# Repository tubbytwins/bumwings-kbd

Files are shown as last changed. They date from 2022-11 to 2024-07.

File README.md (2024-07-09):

# Introduction
BumWings is an ergonomic keyboard design that has several variants with different key configurations.  Some variants use the Waveshare RP2040-zero board which features a Raspberry Pi RP2040 MCU.  Other variants use the Xiao Seeed family of controllers.  Additionally, I've created a new variant (64-key) that uses a nice!nano or compatible MCU.  These designs represent my first attempts at an all-new keyboard PCB design, but obviously I have been influenced by many other keyboard designs (including open-source, closed-source and commercial).

## Design and Implementation

BumWings uses an "un-split" angled ergonomic matrix that has columnar stagger with moderate pinky splay, and features dual inverted T-clusters and modest thumb key clusters.  It is a fairly large board that also gives space for the hands to stay apart and rest at an angle, which works well for me.

The controller board can either be soldered directly to the PCB, or socketed pin headers can alternately be used.

Credit is given to Pete Johanson for the Xiao footprint, circuit design and other aspects from his [revxlp keyboard design](https://gitlab.com/lpgalaxy/revxlp).

This design uses Kailh "Choc" PG1350 key switches.  The board can either be used bare or installed in a case.  For those who prefer a case, I have uploaded a set of PCB case files for a Corne-style board arrangement (with both top plate and bottom plate).  Other case options are still a work in progress.  I am open to using a 3D-printed case, but currently lack the capability (and I don't have a 3D printer); interested individuals who want to help me develop a 3D-printed case should contact me.

## Revisions

The original designs (labeled as "v001", committed in December 2022 and January 2023) represent my first attmept to create a keyboard PCB design.  I learned several things, including the undeniable fact that relatively large PCBs are somewhat more expensive to produce. 

I also learned that my hand-soldering skills were **not** that great.  

These learnings were applied to the "revised" or "remixed" designs (labeled as "v001R", committed in July 2023) which improve on the original "v001" design in some subtle ways.  These are in the "v001R" subdirectory.  I recommend that new users start with the designs in the "v001R" subdirectory.

## Pictures - Work in Progress

Here is a picture of my first prototype build of the initial "v001" RP2040 variant with 54 keys.  It has Kailh Choc Robin switches (mostly).

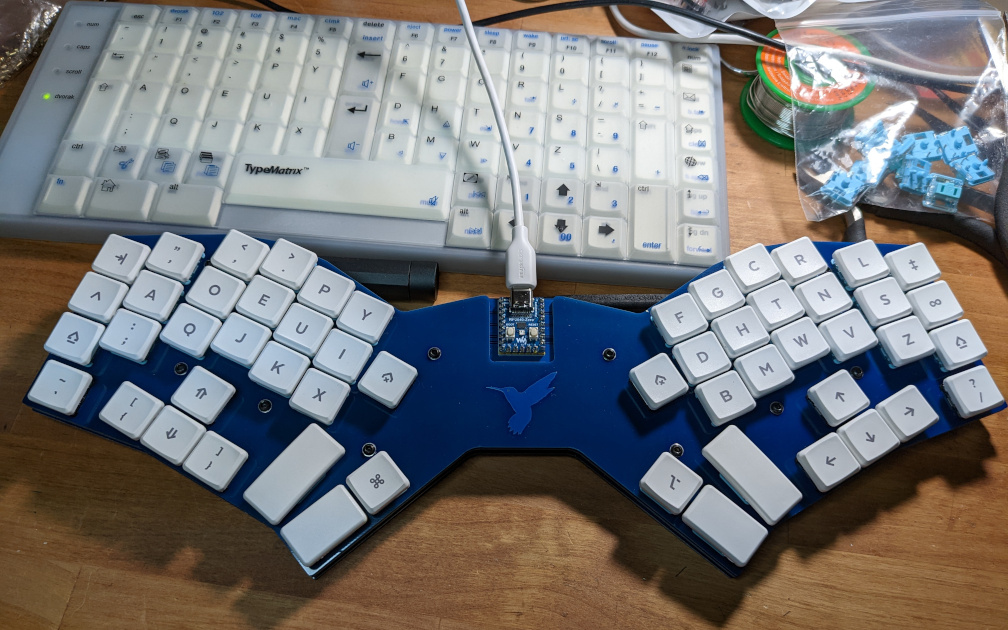
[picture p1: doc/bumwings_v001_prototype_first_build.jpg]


Here is a picture of the new "v001R" RP2040 variant with 64 keys.  This is now my "daily driver" keyboard.  It has Kailh Choc Brown switches (mostly).

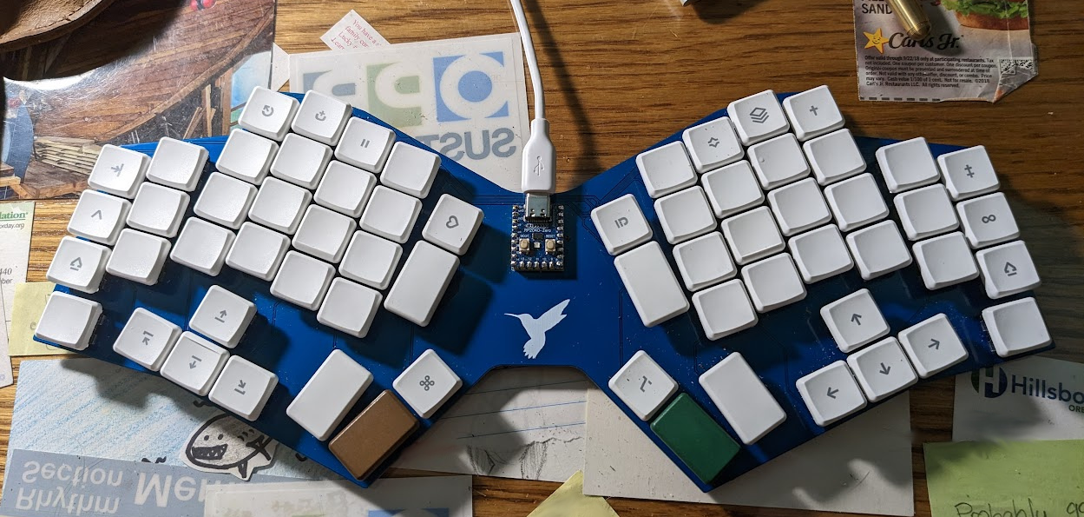
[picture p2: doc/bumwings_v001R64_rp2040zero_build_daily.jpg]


Here are two pictures of the new "v001R" Xiao variant with 64 keys.  This keyboard will be a gift for a friend.  It has Kailh Choc Jade switches (mostly).

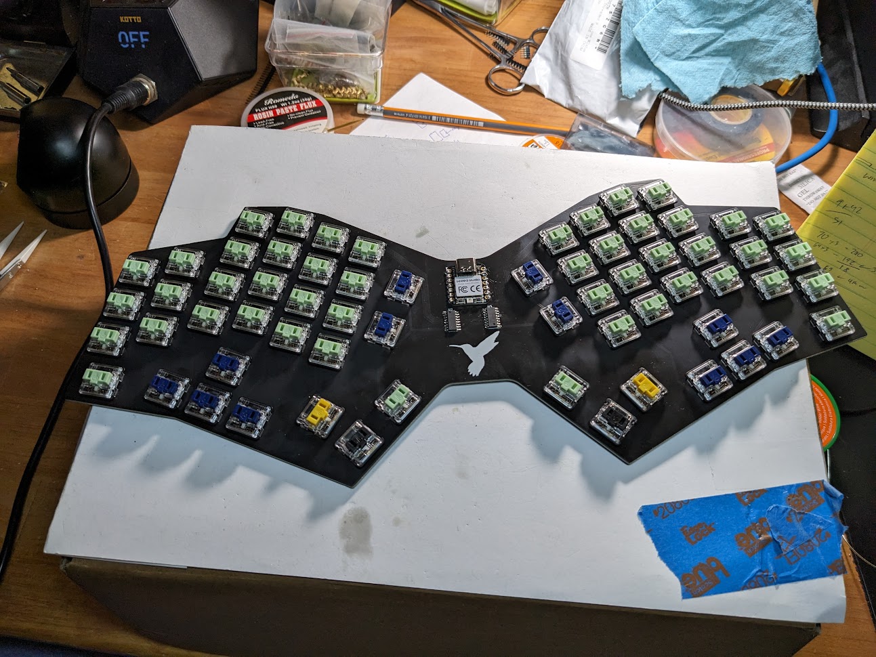
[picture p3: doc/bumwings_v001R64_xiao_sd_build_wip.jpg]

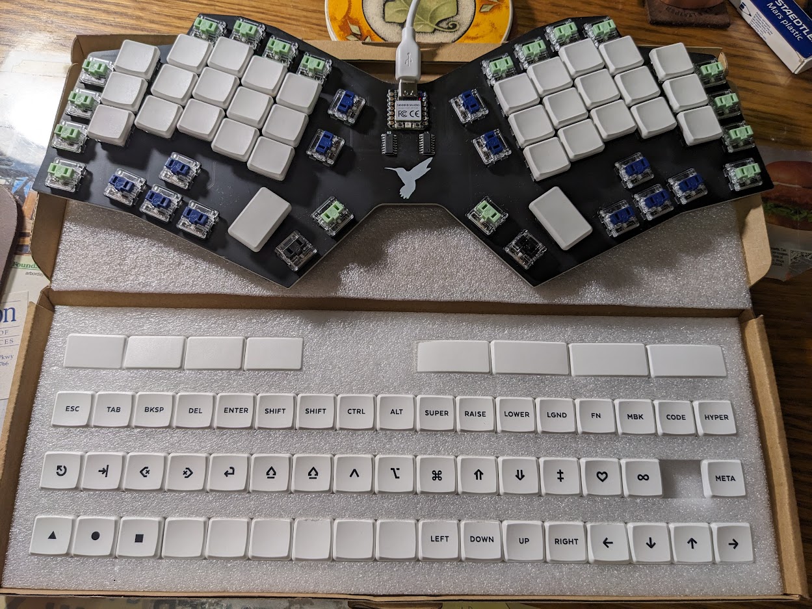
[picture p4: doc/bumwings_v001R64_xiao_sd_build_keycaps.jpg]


Here's another board, this one using the excellent Kailh Choc Sunset switches (mostly) with custom keycaps.

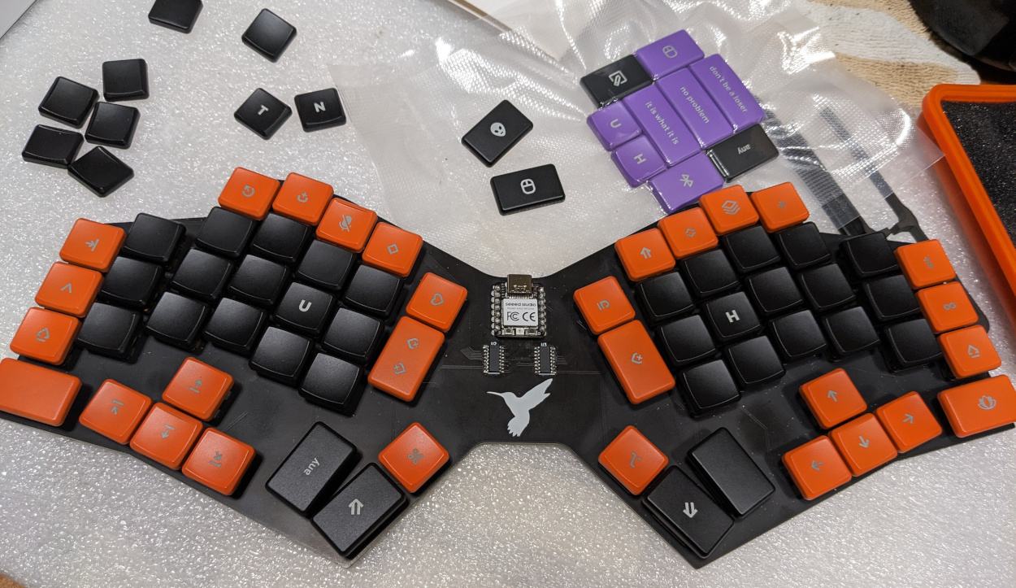
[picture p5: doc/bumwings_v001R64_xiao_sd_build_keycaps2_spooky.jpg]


(more pictures coming soon)

## Future Directions

Update 2024/July: I have some new things to show!

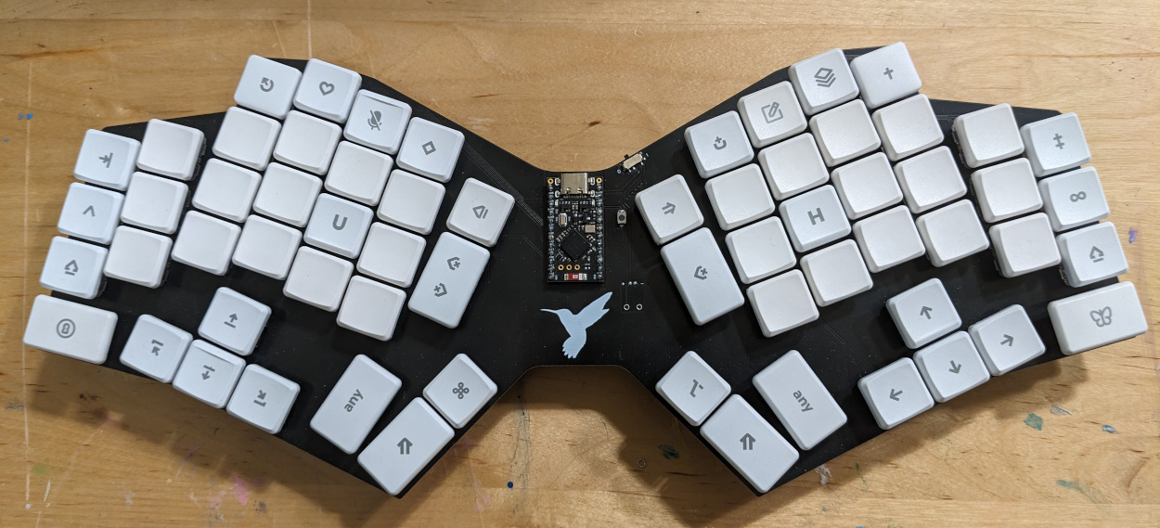
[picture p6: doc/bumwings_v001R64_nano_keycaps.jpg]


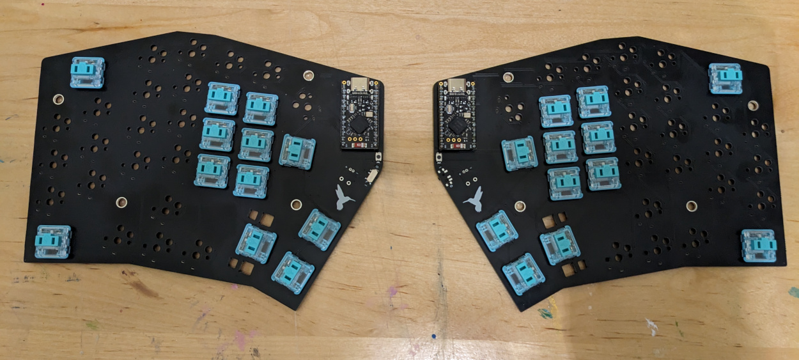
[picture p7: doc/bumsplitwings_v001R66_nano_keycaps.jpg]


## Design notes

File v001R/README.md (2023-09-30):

# V001R

I used JLCPCB to build the prototype PCBs for this version.  These work nicely, perhaps even better than the original "v001" designs.

## List of Variants

*   "pcb_R55_rp2040zero_sd" - simplified, remixed, 55-key direct-soldered PCB based on the Waveshare RP2040 "zero" controller
*   "pcb_R55_xiao_sd" - simplified, remixed, 55-key direct-soldered PCB based on the Seeed Xiao controller
*   "pcb_R64_rp2040zero_sd" - simplified, remixed, 64-key direct-soldered PCB based on the Waveshare RP2040 "zero" controller
*   "pcb_R64_xiao_sd" - simplified, remixed, 64-key direct-soldered PCB based on the Seeed Xiao controller
*   "pcb_R64_nano_sd" - simplified, remixed, 64-key direct-soldered PCB based on the nice!nano controller (and its derivatives)

## Explanation

These variants are different from the "v001" designs in several ways:

*   The overall length of the board was reduced, by about 1 inch.  This brings the hands closer together, but it's still a comfortable arrangement (at least for me).
*   The two hands were rotated "outwards" (i.e., left hand counter-clockwise, right hand clockwise) by a few degrees.  It's a subtle change that helps to reduce the overall width of the board.
*   The shift registers from "v001" (which are 74HC595PW components, in TSSOP-16 size) are now 74HC595D components (in SOIC-16 size) as the former were quite difficult to hand-solder (at least for me).  I messed up at least one prototype board with the TSSOP-16 components, then I learned that the SOIC-16 components were significantly less prone to soldering mishaps.
*   All components are now attached to the top side of the PCB (instead of the bottom side).
*   The case plates were removed, and the new designs are single-PCB caseless builds.  However, you are free to build a case around these if needed.
*   I switched away from the Kailh Choc hot-swap sockets, and went for direct-soldered switches instead.  I have nothing against the hot-swap sockets, but wanted the board design and construction to be simpler for these variants.

I also took the liberty of experimenting with the layout and the number of keys, as follows:

*   The "R55" variants add an extra 1.5U key in the center (between the thumb modifier keys).  You can use this as a space bar, a dedicated enter (carriage return), a layer key or any modifier.
*   The "R64" boards add 10 keys along a new top row, above the alpha keys (for all fingers except the pinky).  You can use these for other commonly accessed symbols, macros, or even delete/tab keys as desired.  The thumb spacebars are also now 1.5U keys instead of 2U keys, and the thumb cluster has been moved upward slightly, in order to reduce the overall width of the board.  In practice, 1.5U spacebars are quite usable, and you could probably use 1.75U spacebars (if the key caps were available).

## Pictures

The board renders for the 55-key and 64-key Waveshare RP2040-zero variants are shown below:

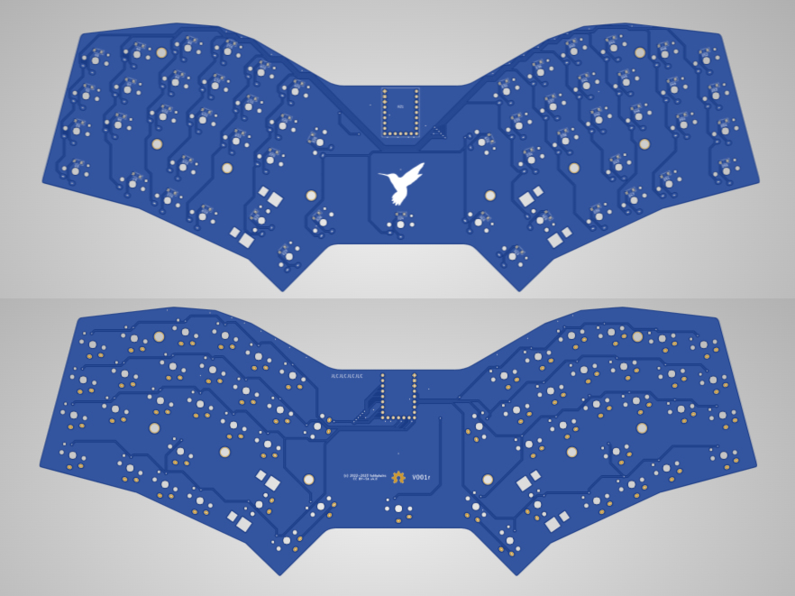
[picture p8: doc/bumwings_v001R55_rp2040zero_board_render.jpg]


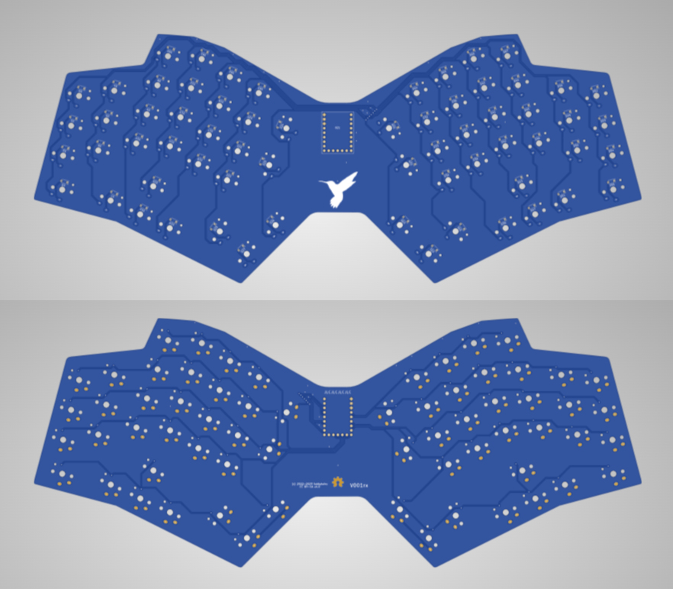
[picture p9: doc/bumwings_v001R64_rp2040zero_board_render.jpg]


The board renders for the 55-key and 64-key Xiao Seeed variants are shown below:

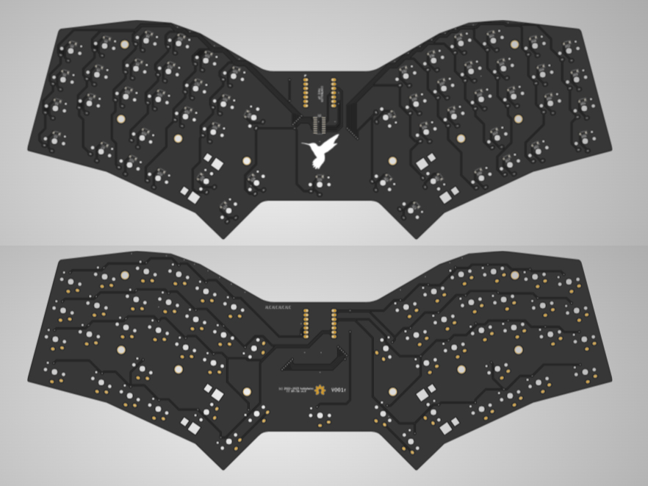
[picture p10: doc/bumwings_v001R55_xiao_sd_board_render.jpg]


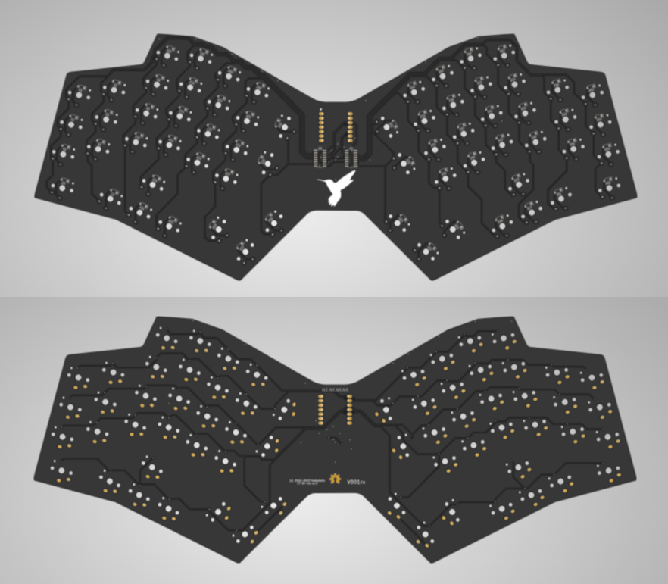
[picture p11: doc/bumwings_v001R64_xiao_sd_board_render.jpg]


The board render for the 64-key nice!nano variant is shown below:

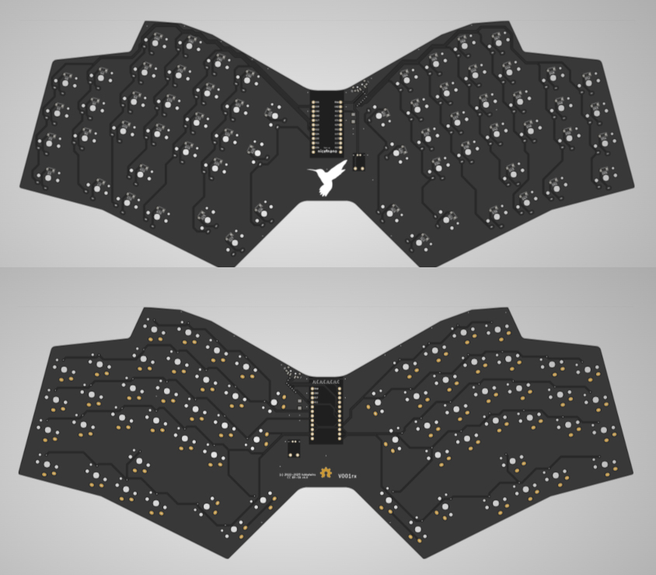
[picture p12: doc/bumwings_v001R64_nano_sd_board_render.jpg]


(I haven't made a 55-key nice!nano variant yet.  If anyone's interested, please feel free to ask.)

## Bill of Materials

## All variants

Diodes:  D_SOD-123 (either 55x or 64x)

Sockets:  none (since key switches are direct-soldered)

Key caps:  MBK (either plain, or with legends, at your discretion)

Other resistors/etc:  none

### Waveshare RP2040 variant

MCU:     Waveshare RP2040 "zero" (23-pin module with USB-C port) - you can find these on Amazon for a higher price, or on Aliexpress or eBay for a lower price.  They can either be plain, or with pre-soldered pin headers.

### Xiao Seeed variant

MCU:     Xiao Seeed controller of your choice - you can find these from many suppliers.

Shift Register:  74HC595D (in SOIC-16 format) - you can find these from many suppliers.  The 55-key variants use 1 of these, and the 64-key variants use 2 of these in a chained configuration.

### nice!nano variant

MCU:     nice!nano, or one of the other derived controllers that you can find on Aliexpress for a lower price.  These will be soldered face-up.
Reset switch:  optional

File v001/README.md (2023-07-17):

# V001

I used JLCPCB to build the first prototype PCBs for this version.  It works nicely.

See "info.md" for more information about the background and inspiration for this keyboard design.

## List of Variants

*   "pcb_core52840" - 54-key hot-swap PCB based on the Waveshare Core52840 module
*   "pcb_rp2040zero" - 54-key hot-swap PCB based on Waveshare RP2040 "zero" controller
*   "pcb_xiao" - 54-key hot-swap PCB based on the Seeed Xiao controller
*   "pcb_xiao_s" - simplified 54-key direct-soldered PCB based on the Seeed Xiao controller

## Pictures

The board renders for the Waveshare RP2040-zero variant are shown below:

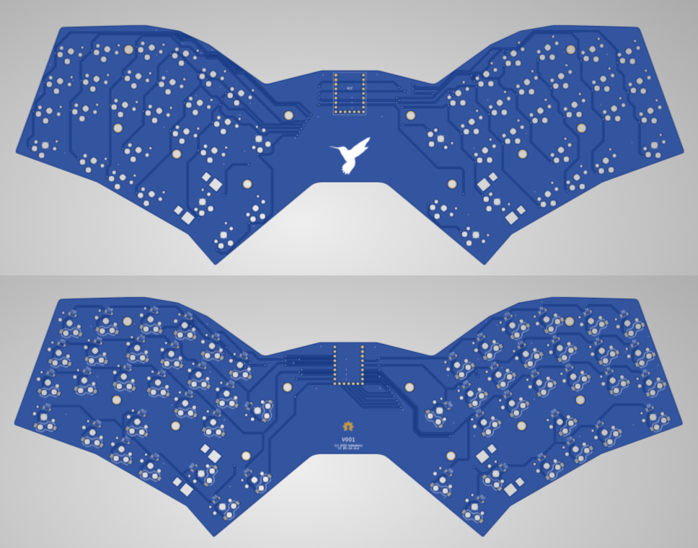
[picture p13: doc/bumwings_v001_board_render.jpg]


The board renders for the Xiao Seeed variant are shown below:

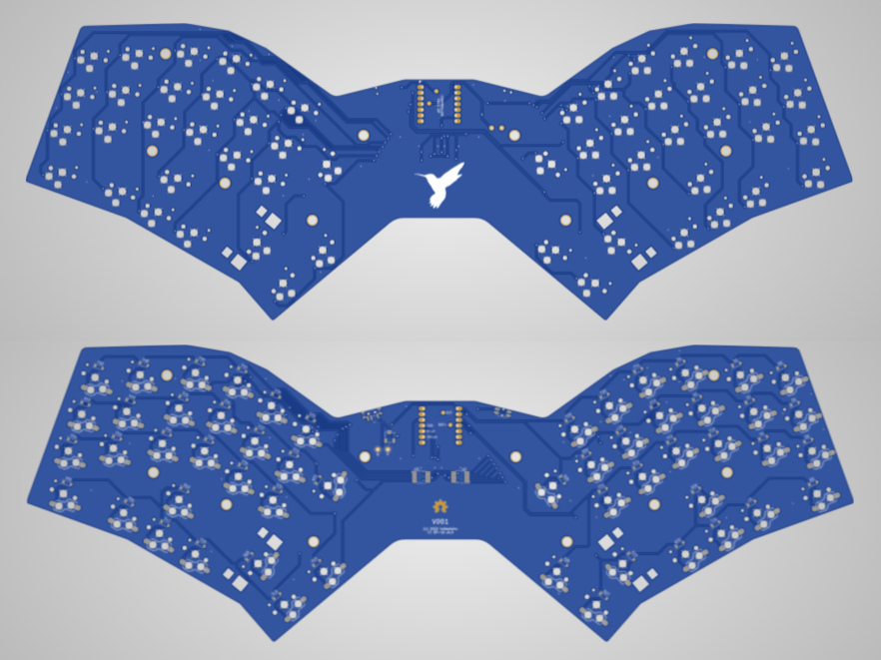
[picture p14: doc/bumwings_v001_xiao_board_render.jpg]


The board renders for the slightly simplified Xiao Seeed variant are shown below:

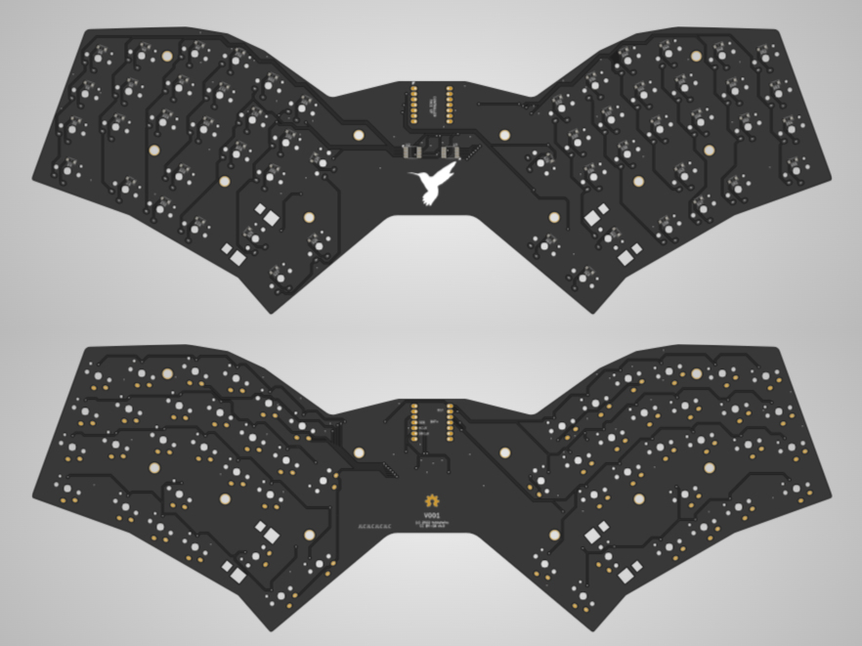
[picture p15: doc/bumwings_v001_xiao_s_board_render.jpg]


## Bill of Materials

## All variants

Diodes:  54x D_SOD-123

Sockets:  54x Kailh Choc hot-swap (for all variants except "pcb_xiao_s") (again, you will need 54 of them)

Key caps:  MBK (either plain, or with legends, at your discretion)

Other resistors/etc:  none

### Waveshare RP2040 variant

MCU:     Waveshare RP2040 "zero" (23-pin module with USB-C port) - you can find these on Amazon for a higher price, or on Aliexpress or eBay for a lower price.  They can either be plain, or with pre-soldered pin headers.

### Xiao Seeed variant

MCU:     Xiao Seeed controller of your choice - you can find these from many suppliers

Shift Register:  2x 74HC595PW or SN74HC595PW (in TSSOP-16 format) - you can find these from many suppliers, usually around USD $1.50 for a pack of 10

Reset switch and power switch:  optional, stay tuned...

### Xiao Seeed Simplified variant

MCU:    Xiao Seeed controller (as above)

Shift Register:  2x 74HC595PW or SN74HC595PW (in TSSOP-16 format)

No reset or power switch.  This variant is intended for non-wireless (and non-battery-powered) builds.  The Xiao Seeed RP2040 controller works very well for this variant, and I expect that the SAMD21 controller would also work very well.

For this variant, all components are direct-soldered to the front of the PCB (except the key switches, obviously).

### Waveshare Core52840 variant

MCU:     Waveshare Core52840 module, featuring Nordic Semiconductor's nRF52840

Alternate: HolyIOT 18010 module (which is apparently pin-compatible...)

Other components as follows:  (based heavily on Rafael Yumagulov's "Dao-Choc-BLE" board, but I replaced all 0603-size components with 1206-size components, to make it easier for hand-soldering)
https://github.com/yumagulovrn/dao-choc-ble

| Reference | Name | Package  | Value | Qty  |
|---|---|---|---|---|
| BT1 | JST | ? | 1.25mm 2pin 90° | 1 |
| C1-C2, C4-C5 | Capacitor | 1206 | 10uF | 4 |
| C3 | Capacitor | 1206 | 1nF | 1 |
| C6-C7 | Capacitor | 1206 | 4.7uF | 2 |
| D0-D55 | Diode | SOD-123  | 1N4148WS | 54 |
| D56 | Diode | SOD-123  | 1N5819W | 1 |
| D57 | LED | 1206 | BLUE | 1 |
| D58 | LED | 1206 | RED | 1 |
| F1 | Fuse | 1206 | 500mA | 1 |
| J1 | USB Receptacle | ? | ? | 1 |
| Q1 | P-Mosfet | SOT-23 | AO3401A | 1 |
| R1-R2 | Resistor | 1206 | 5.1k | 2 |
| R3 | Resistor | 1206 | 4.7 | 1 |
| R4 | Resistor | 1206 | 1M | 1 |
| R5a | Resistor | 1206 | 750k | 1 |
| R5b | Resistor | 1206 | 56k | 1 |
| R6-R7 | Resistor | 1206 | 1k | 2 |
| R8 | Resistor | 1206 | 2M | 1 |
| R9 | Resistor | 1206 | **RPROG**** | 1 |
| R10 | Resistor | 1206 | 100k | 1 |
| SW0-SW55 | Kailh Choc Hotswap Socket | ? | ? | 54 |
| SW56 | SPDT Switch | ? | MSK-12C02 | 1 |
| SW57 | Tactile Button | ? | TS-1086E | 1 |
| U1 | MCU | ? | Core52840 | 1 |
| U2 | ESD Protection IC | SOT-23-6 | USBLC6-2SC6 | 1 |
| U3 | Voltage Regulator IC | SOT-23-5 | XC6220 | 1 |
| U4 | Battery Charging IC | SOT-23-5 | MCP73831 | 1 |

In the Dao-Choc-BLE design, the designer offered an alternate value of 820k for "R5"; however, for such a voltage sensing circuit (for battery status) a resistor of 820k will give somewhat invalid values.  In my design, I opted to use two resistors that added up to 806k, which is the recommended value.

**RPROG**** Value depends on your battery capacity. For 300mAh battery should be 3.3K

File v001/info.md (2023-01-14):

# More Information about BumWings

## History and Design Goals

I've been using TypeMatrix keyboards (both EZR-2020 original and EZR-2030) for nearly 2 decades.  In 2004 (or so) I taught myself to touch-type in DVORAK, which resolved many ergonomic issues for me.  Long story short: I still love the TypeMatrix keyboards, but I started noticing that my hands and wrists were feeling bad after a long day of typing.  I eventually traced this down to the hand/wrist position: these keyboards require the hands to be fairly close together, although not as close as a typical QWERTY keyboard.

After researching split keyboards for some time, I went out and bought a gently used Ergodox-EZ from eBay.  It worked nicely, and after some adjustment I was able to customize it to do whatever I needed it to do.  However, some issues kept me from using it effectively:

*  Pinky row stagger was nice, but not sufficient; I have quite short pinky fingers, and it was always a reach.
*  Reliance on the "mod" row (below the lower row) for modifiers;  I could have made this different, but these are harder to reach.
*  Hard to reach the "number row" (above the upper row); again with the short fingers thing.
*  Too many keys in the thumb clusters; using the 3 vertically stacked 1U keys is good for some usage, but not great for fast typing (in practice).
*  Increased key travel (compared to the trusty TypeMatrix models) with typical Cherry switches means more work to type *and* more impact on fingers, as I find that I need to really bang the things to get the effective feedback that I need to touch-type with any speed.

Other issues were postural and positional: having the two halves of the Erdogox spaced apart meant that it was possible to put my mouse and mousepad between them; however, I keep finding that I reach outwards (instead of inwards) to find the mouse.  Old habits truly do die hard!

So I kept researching other keyboards, bought a Corne LP kit (from littlekeyboards.com) to try out that approach, and kept researching.  I ran across several interesting layouts, including:

*   Reviung-41 and its variants, which kept both hands together *but* put both halves at an angle, suggesting better posture; and
*   Pteron-56 and its variants, which did much the same thing but had more keys.

However, both of these only supported Cherry-MX key switches, and I felt that using Kailh Choc key switches would give me a typing experience that was closer to the TypeMatrix keyboards (with reduced travel).  I also researched the Hummingbird designs (by PJE66) but decided against using this, as I didn't really want to have to re-learn a new keyboard layout to use this, especially one that relies on chording for any of the alphas or the main punctuation.  (It's not a bad idea in theory, but at this point I'm committed to staying with the DVORAK layout.)

After more research, I found many interesting and worthy designs that offered different strengths and advantages, but none of them quite did what I wanted to do.  So, I installed KiCad, played around with "modding" several of these other layouts (thanks to the design files being available in GitHub; open source hardware design is awesome!), watched numerous videos by Ben Vallack, and then took the leap by deciding to create my own layout.

I would say that this design of mine is "from scratch" but obviously I have been influenced by many other designs.  I'll list most of them here; it's hard to be thorough but these have obviously given me inspiration for various aspects of this design.

*   TypeMatrix EZR-2020 and EZR-2030 (the classics!)
*   Ergodox and its variants, including Ergodox-EZ
*   Corne Choc LP (hot-swap, both V2 from foostan and V3 from Daysgobye)
*   Corne-Xiao (by Lehmanju)
*   Dao-Choc-BLE (by Rafael Yumagulov)
*   Hillside (by mmccoyd; all variants)
*   Hotreus62 (by beekeeb)
*   Humla (by jimmerricks)
*   Hummingbird (by PJE66; unfortunately, no KiCad source is currently available)
*   Iris PE (by keebio; closed source design)
*   Jorne (by Joric)
*   Kyria (by splitkb.com; closed source design)
*   Lily58 (by kata0150)
*   One42 (by Cyril279)
*   Pteron-56 and its variants (by KrakenJokes)
*   Reviung-41 (by gtips) and its variants
*   RevLP (by Cyril279) and RevXLP (by Pete Johanson)
*   VColChoc44 (which integrated an on-board RP2040 MCU)
*   Wren (by Walter Hanley; all variants over time)
*   Zaphod (by Pete Johanson)

One thing to note: I could find no designs that used the Waveshare RP2040-zero module, which was a bit disappointing to me.  So I used this as a vehicle to prove that it could be used in a keyboard design.  There really is a lot to like about this module: it has more IO pins available than the Xiao Seeed RP2040 module, and only takes up less than one square inch of space.  The Waveshare RP2040-zero module addresses the limitations of the Xiao Seeed module without extra components.

> FYI - I am not sponsored by Waveshare, nor am I receiving compensation in any way.

UPDATE:  I decided to make a Xiao Seeed variant after all!  The circuit for this variant uses two (2) 74HC595 shift register ICs to drive the column lines, as there are not enough IO pins to drive all the column and row lines.

NOTE:  I am not planning to make a ProMicro compatible variant of this design at this time.

Finally, a brief note about the name ("BumWings").  I'm not really going to give a deep explanation for that: I come up with silly names for things all the time, and most of them are based on meats or other food items (which makes this an exception).  The words "bum" and "wings" happened to pop into my head and the combination made sense to me at the time, and so I kept it.  It isn't meant to be pejorative or insulting.  If you don't like it, feel free to clone the repo, adapt the design to your needs, and change the name to your liking.  This is what open source hardware design allows you to do.

## Links

https://www.waveshare.com/rp2040-zero.htm

## Mounting Options

Although both the Waveshare RP2040-zero module and the Xiao Seeed modules do have castellated pins and can theoretically be mounted directly to SMD pads, this design doesn't support that.  I figured that I wasn't ready to try this yet (since my soldering skills are barely passable at best) and also the narrow central neck of the keyboard PCB didn't need to be made any smaller, since the Waveshare module's RP2040 chip is mounted on the underside.  So my decisions were made based on simplicity.  The Waveshare module does have 20 IO pins that are accessible via the edge pins, so it is possible to mount this similar to a Pro Micro or Elite-C (i.e., with pin headers) and you wouldn't even need to worry about the remaining 9 IO pins on the underside.  By contrast, the Xiao Seeed modules do not have extra IO pins on the underside.

## About the Matrix

The keyboard matrix has 14 columns and 4 rows -- and yes, I know this is not as efficient as it could be...

* Row_up is used for the upper row (above home row)
* Row_home is used for the home row (obviously)
* Row_dn is used for the lower row, plus some thumb cluster keys (1U)
* Row_mod is used for the remaining thumb cluster keys, modifier keys, and the arrow clusters (inverted T)

For columns, X is either L for left hand, or R for right hand.

* Col_Xp2 is the secondary pinky finger alphas, and the lower corner modifier (1.5U outermost).
* Col_Xp1 is the primary pinky finger alphas, and one key from the arrow cluster (outermost).
* Col_Xr is the ring finger alphas, and another key from the arrow cluster (center lower).
* Col_Xm is the middle finger alphas, and another key from the arrow cluster (center upper).
* Col_Xi1 is the primary index finger alphas, and the remaining key from the arrow cluster (innermost).
* Col_Xi2 is the secondary index finger alphas, and the primary thumb key (2U) in the cluster.
* Col_Xt is the innermost 1.5U keys (which will both be Backspaces for me) plus the remaining 2 thumb keys (1.5U and 1U) in the cluster.

On the board, the key switches are labeled as SW0 through SW55.  Note that SW24 and SW28 do not exist; these would have been on Col\_Xt and Row\_up.

## Layout Recommendations

I use DVORAK, so I designed this to work well with DVORAK.  You can adapt this to use Colemak, Colemak-DH, QWERTY (but why?) or any other layout that works best for you.

Here are some other recommendations:

*  The 1.5U keys on the home row (index finger) should be used as Backspaces.  I use two Backspaces, since I "grew up" using TypeMatrix keyboards and the original ones had two backspaces in the middle.  Don't knock it if you haven't tried it, since using alternate Backspaces for each index finger is a great way to get rid of embarrassing typos, especially if your brain is quicker than your fingers and you don't see the typo until a few more characters have been typed.  If this doesn't work for you, then one of them can become a Delete or Return, or you can remap these to whatever works for you.
*  The arrow clusters (remote WASD) would work very well as obvious arrow keys for one side, and navigation keys (Home/End/PgUp/PgDn) for the other side.  You can obviously choose which cluster works better for each use.  The example ZMK configuration shows how these are used for arrows and navigation.
*  The large 2U thumb keys would work as Space and/or Enter, and optional chording modifiers with home-row keys.  Some examples below:
   *  Thumb + index = Ctrl
   *  Thumb + middle = Shift
   *  Thumb + ring = Alt
   *  Thumb + pinky = Win/Super
   *  Thumb + lower corner modifier (1.5U) = Meh
   *  In my example ZMK configuration, both 2U thumb keys are Space.
*  The 1.5U thumb keys would work very well as Delete and Tab, and optional chording modifiers with other keys (see above).
   *  Alternately, these keys can be used for accessing layers (Numbers, Symbols, etc.)
   *  In my example ZMK configuration, the left 1.5U thumb key is a momentary layer key, and the right 1.5U thumb key is either a Return (if tapped) or another layer key (if held).
*  The 1U thumb keys can be used for any purpose, including other modifiers or perhaps MouseKeys (a layer).
   *  In my example ZMK configuration, the left 1U thumb key is the GUI (win/cmd) modifier, and the right 1U thumb key is the Alt modifier.

## Case Options

This repo also contains PCB files for a top plate (with hummingbird art) and a bottom plate (with bigger hummingbird art).  This was heavily inspired by the Corne case.

I'm also working on a metal top plate design.  This could either be full-size, or made in a split (half) version.  The intended case is a wooden board (or "plinth") that can house the PCB and the metal top plate.  My first concept will likely be based on a bamboo cutting board, but I'll need to do the routing myself to hold the PCB, with an inset for the metal top plate so it sits flush with the upper wood surface.  Also, I'll probably need to cut the board at an angle and re-join it along the center line with one side flipped, so it has a chunky "V" shape.  This should hold the metal top plate but I need to confirm this.  I don't have all the woodworking tools to make this happen, but I know some people who do...

Both cases will leave a gap around the RP2040 module.  This can be kept open for visibility, or optionally a cover could be made.  My only cover ideas at this point are either acrylic or solid wood.  The wood cover should have a mini "light-pipe" so the onboard LED can be seen when the cover is installed.  (That way, I can theoretically use the LED to indicate which layer is selected.)

## Firmware Options

ZMK works nicely, as long as you have a fork that is based on Pete Johanson's RP2040 support branch.  I recommend using either of these two forks:

https://github.com/glebsexy/zmk/tree/rp2040-zero-plus-combos-fix
https://github.com/tubbytwins/zmk/tree/rp2040-zero-plus-combos-fix

Much credit goes to Glebsexy for doing the heavy lifting of getting the Waveshare RP2040-zero board added to ZMK!  I went ahead and hacked together my own changes *before* I found that this work was already done, so I've moved over to use their work.

Example ZMK config is here:  https://github.com/tubbytwins/bumwings-zmk-config  (only supports Waveshare at the moment... stay tuned...)

QMK also works nicely.  I've set up a fork at the link below with the board definition, as well as some sample layouts.

https://github.com/tubbytwins/qmk_firmware_bumwings/tree/add_bumwings

KMK has not yet been tested, but should work (in theory).

## Wish List and Future Plans

*  Add a Type-C port for expansion options (such as a numpad on the left side)
   *  Figure out how to get I2C working.
   *  Perhaps use an IO expander instead of a separate MCU?  Not trying to save cost here, but a separate MCU seems to be overkill for the job.
   *  Make it hot-swap capable; if it's plugged in, the RP2040 sees it and uses it; if not, it goes along without it.  My spouse is using an old Microsoft Sidewinder (X4?) keyboard that has a detachable numpad, which is a really good idea and *more keyboards* should support this concept.
   *  Type-C seems nice: I really don't want to use TRS or TRRS connectors for this.  However, it seems that very few companies sell "short" (<18 inch) Type-C cables that are known to work.  Keebio is one of the few companies that does, for the Iris keyboard and others.
*  Make a true split version that could be integrated into a single plinth (or wooden board) with a tenting angle.
*  Add an optional display: some companies seem to be making 1.4" rectangular LCDs with rounded corners.  It would be nice to have one of these showing layer info and status in real-time while I type.
*  Make another version that supports the Waveshare RP2040 LCD MCU module, which has a circular LCD screen and looks really cool.

## Feedback

Please feel free to adapt this design to meet your needs, and share your results!  I'm eager to get feedback on how well this keyboard works for others.  If you have any suggestions for improvements **or** alternatives that would make this keyboard more useful, please let me know.

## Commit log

2022-11-17 Adding v001 keyboard PCB design files, images and more information.
    [bumwings_v001.kicad_sch]
2022-11-17 Updating README to include an image of the first prototype build.
2022-11-17 Adding top and bottom plate design files.
    [bumwings_plate_bottom_v001.kicad_pcb, bumwings_plate_top_v001.kicad_pcb]
2022-11-17 Added image of rendered PCB design.
2022-11-21 Updated the Kailh hot-swap socket footprints to make them a bit easier for hand-soldering. Fixed some minor routing nuisances.
2022-12-19 Adding open source hardware logo to the back of the board.
2022-12-19 Renaming "pcb" directory to "pcb_rp2040zero".
    [bumwings_v001.kicad_sch]
2022-12-19 Adding new Xiao Seeed variant of the PCB, for those who prefer these controllers over the Waveshare RP2040-zero. Note that this is completely untested at the moment; stay tuned for updates on how thi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
    [bumwings_v001_xiao.kicad_sch]
2022-12-19 Added board render image of Xiao Seeed variant.
2022-12-23 Cleaned up some routing, adjusted location of reset switch.
2022-12-24 Surprise! Here is my first attempt at a wireless BLE variant. This is completely untested at the moment. I will try to get the PCBs produced shortly and share results. PCB uses either the Waveshare C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
    [bumwings_v001_core.kicad_sch]
2023-01-08 Adding the Gerber files for PCBs as well as the case plates.
2023-01-14 Updated README with full BOM for Core52840 wireless variant.
2023-07-17 Adding new remixed "v001R" variants, which have either 55 or 64 keys and have minor adjustments to the overall key arrangement. Adding new simplified Xiao Seeed variant. Updated pictures of new board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
    [bumwings_v001R55_rp2040zero_sd.kicad_sch, bumwings_v001R55_xiao_sd.kicad_sch, bumwings_v001R64_rp2040zero_sd.kicad_sch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]
2023-07-17 Adding the Gerber files for the newest PCBs.
2023-09-30 Adding a 64-key nice!nano variant.
    [bumwings_v001R64_nano_sd.kicad_sch]
2023-10-02 Oops, the original render for v001R/pcb_R64_nano_sd showed the front side twice. That has been fixed now.
2024-07-09 New pictures of the latest PCB prototypes, including a split version!
